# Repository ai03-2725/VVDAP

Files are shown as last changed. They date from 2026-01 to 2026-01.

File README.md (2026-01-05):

# VVDAP
Variable voltage isolated DAPLink programmer  

**Warning:** Currently untested.  
If testing, proceed at your own risk.  

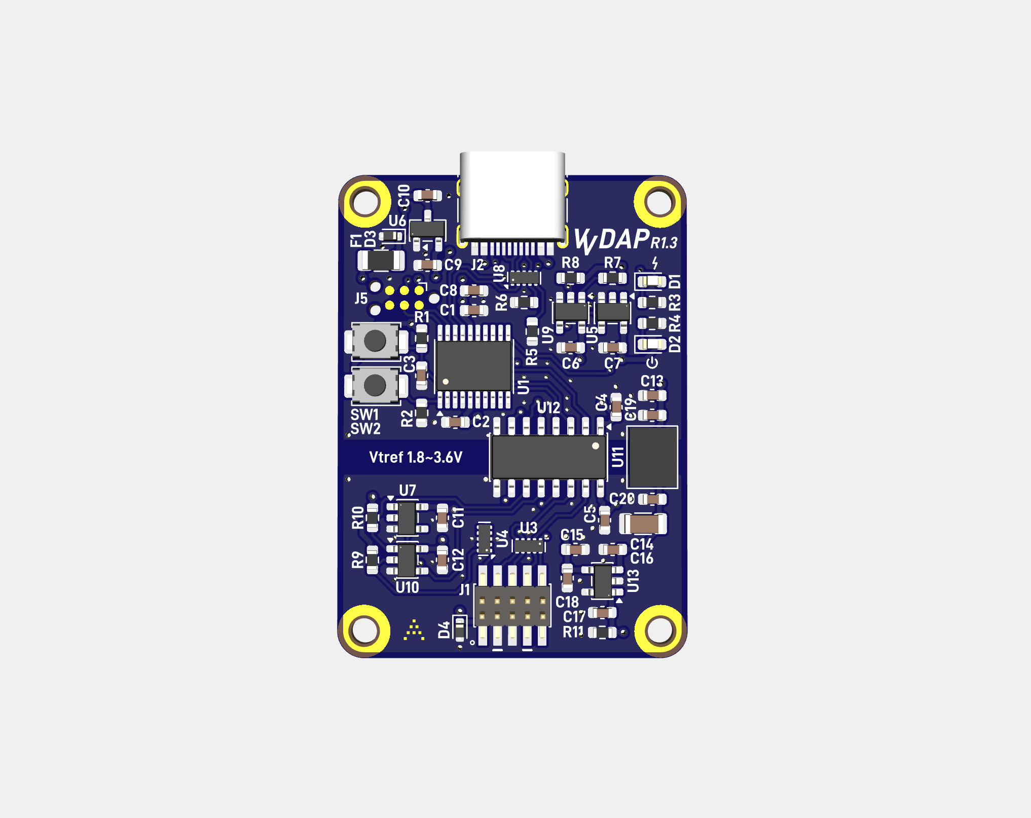
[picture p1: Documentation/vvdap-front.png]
Front

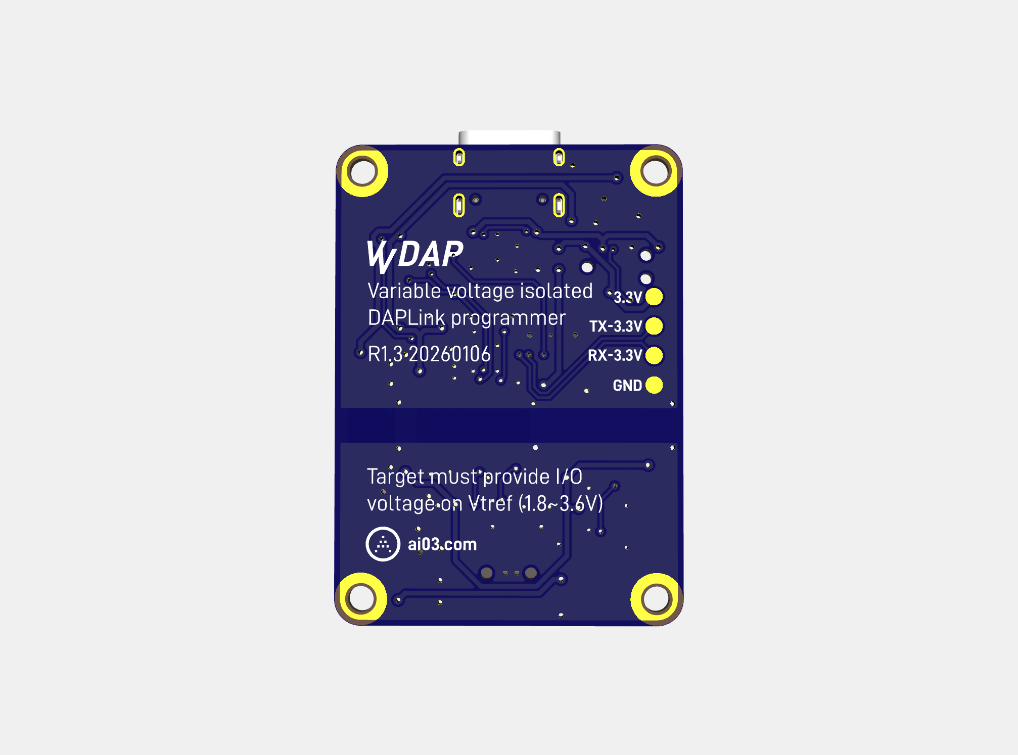
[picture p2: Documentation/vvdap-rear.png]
Rear


## Features
- DAPLink capabilities
  - [DAPLink](https://daplink.io) programming device for flashing Arm Cortex devices
  - Standard 10-pin (5x2) 1.27mm pitch Cortex debug connector for connection to target
  - Exposes UART pins - for future variable-voltage UART module addon via spring-loaded headers
- Variable voltage
  - Variable I/O voltage from 1.8 to 3.6V which self-adjusts to match the target VCC voltage provided on Vtref pin of debug header
- Protection
  - Full isolation between host and target to avoid ground loops or damage to host
  - ESD protection on USB lines and debug connector I/O
  - Polyfuse on USB VBUS
- Modern nice-to-haves
  - USB-C 
  - Fairly compact single-board solution
  - Relatively straightforward to solder at home with a reflow plate and (possibly 3D-printed) solder paste stencil
  - Very affordable (likely <15 USD) compared to the multi-hundred dollar commercial programmers

## Credits
This project builds upon the shoulders of giants - credits go to the following for nearly all of the heavy lifting.  
- [XIVN1987's DAPLink port](https://github.com/XIVN1987/DAPLink) to the CH32V203 microcontroller
- [XIVN1987's reference CH32V203/AT32F425 hardware design](https://oshwhub.com/xivn1987/daplink) for the above port
- [盐汽水-BD4USQ's DAPLink isolator design](https://oshwhub.com/yanqisui/dap-jlink-ge-li-diao-shi-kuo-zhan-ka) (and in turn the projects which it credits) which makes push-pull SWDIO possible over unidirectional isolators/transcievers 

## Changes from the above
- Swapped the digital I/O isolator to an ADuM162N capable of reaching low I/O voltage levels
- Added ESD protection on USB and I/O lines using TPD4E05U06 and ESD5Z5V0 TVS diodes
- Isolated voltage supply rail using the MIE1W0505/R05C1TF05S compact isolated DC/DC converter
- Added a TPS7B4250 tracking LDO to replicate the voltage provided on the Vtref pin of the debug header from the isolated supply rail, which in turn powers the secondary side of the I/O isolator and push-pull splitter
- Changed output connector to a 10-pin (2x5) 1.27mm pitch Cortex debug header
- Removed all power output capabilities 
  - Target should self-power to avoid potentially dangerous voltage mismatches, reverse voltage injection into circuitry not designed to withstand it, or voltage injection into batteries
- Misc component swaps

## Todo
- Produce and test
- Make a 3D printed case
- Make a variable voltage UART module which stacks onto the main board

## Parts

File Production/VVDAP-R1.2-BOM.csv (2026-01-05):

Reference | Qty | Value | DNP | Footprint | Description
C1,C2,C3,C4,C5,C6,C7,C11,C12,C17,C19,C20 | 12 | 0.1uF |  | Capacitor_SMD:C_0603_1608Metric | Ceramic capacitor, 0603, X7R, min 10V
C8,C9,C10,C15,C16,C18 | 6 | 1uF |  | Capacitor_SMD:C_0603_1608Metric | Ceramic capacitor, 0603, X7R, min 10V
C13 | 1 | 10uF |  | Capacitor_SMD:C_0603_1608Metric | Ceramic capacitor, 0603, X7R, min 10V
C14 | 1 | 22uF |  | Capacitor_SMD:C_1206_3216Metric | Ceramic capacitor, 1206, X7R, min 10V
D1 | 1 | LED-Red |  | LED_SMD:LED_0603_1608Metric | Light emitting diode, 0603, Red
D2 | 1 | LED-Green |  | LED_SMD:LED_0603_1608Metric | Light emitting diode, 0603, Green
D3,D4 | 2 | ESD5Z5V0 |  | Diode_SMD:D_SOD-523 | ESD Protection Diode, SOD-523
F1 | 1 | Polyfuse |  | Fuse:Fuse_1206_3216Metric | Resettable PTC fuse, 1A hold, 10V min
J1 | 1 | FTSH-105-01-L-DV-K |  | locallib:FTSH-105-01-L-DV-K | FTSH-105-01-L-DV-K 1.27mm pitch 2x5 pin connector
J2 | 1 | USB_C_Receptacle_USB2.0_16P |  | Connector_USB:USB_C_Receptacle_HRO_TYPE-C-31-M-12 | HRO TYPE-C-31-M-12 USB Type-C Receptacle connector
R1,R2 | 2 | 10k |  | Resistor_SMD:R_0603_1608Metric | Resistor, 0603
R3,R4,R7,R8,R9,R10 | 6 | 1k |  | Resistor_SMD:R_0603_1608Metric | Resistor, 0603
R5,R6 | 2 | 5.1k |  | Resistor_SMD:R_0603_1608Metric | Resistor, 0603
R11 | 1 | 1M |  | Resistor_SMD:R_0603_1608Metric | Resistor, 0603
SW1,SW2 | 2 | SW_Push |  | Button_Switch_SMD:SW_SPST_TS-1088-xR020 | TS-1088 family 3x4mm pushbuttons
U1 | 1 | CH32V203F6P6 |  | Package_SO:TSSOP-20_4.4x6.5mm_P0.65mm | CH32V203F6P6 Microcontroller
U3,U4,U8 | 3 | TPD4E05U06DQA |  | Package_SON:USON-10_2.5x1.0mm_P0.5mm | 4-Channel ESD Protection for Super-Speed USB 3.0 Interface, USON-10
U5,U7 | 2 | SN74LVC1G07DBVR |  | Package_TO_SOT_SMD:SOT-23-5 | Single Buffer Gate, Open Drain, Low-Voltage CMOS
U6 | 1 | XC6206P332MR |  | Package_TO_SOT_SMD:SOT-23-3 | Positive 60-250mA Low Dropout Regulator, Fixed Output, SOT-23
U9,U10 | 2 | SN74LVC1G66DBVR |  | Package_TO_SOT_SMD:SOT-23-5 | Single Bilateral Analog Switch, SOT-23-5/SC-70-5
U11 | 1 | MIE1W0505 |  | locallib:MIE1W0505 | Thin 4x5mm isolated DC-DC module with symmetrical pads - MIE1W0505, R05C1TF05S, and equivalents
U12 | 1 | ADuM162N1BRZ |  | Package_SO:SOIC-16_3.9x9.9mm_P1.27mm | ADuM162N1BRZ digital I/O isolator
U13 | 1 | TPS7B4250 |  | Package_TO_SOT_SMD:SOT-23-5 | TPS7B4250 tracking LDO
Total | 52

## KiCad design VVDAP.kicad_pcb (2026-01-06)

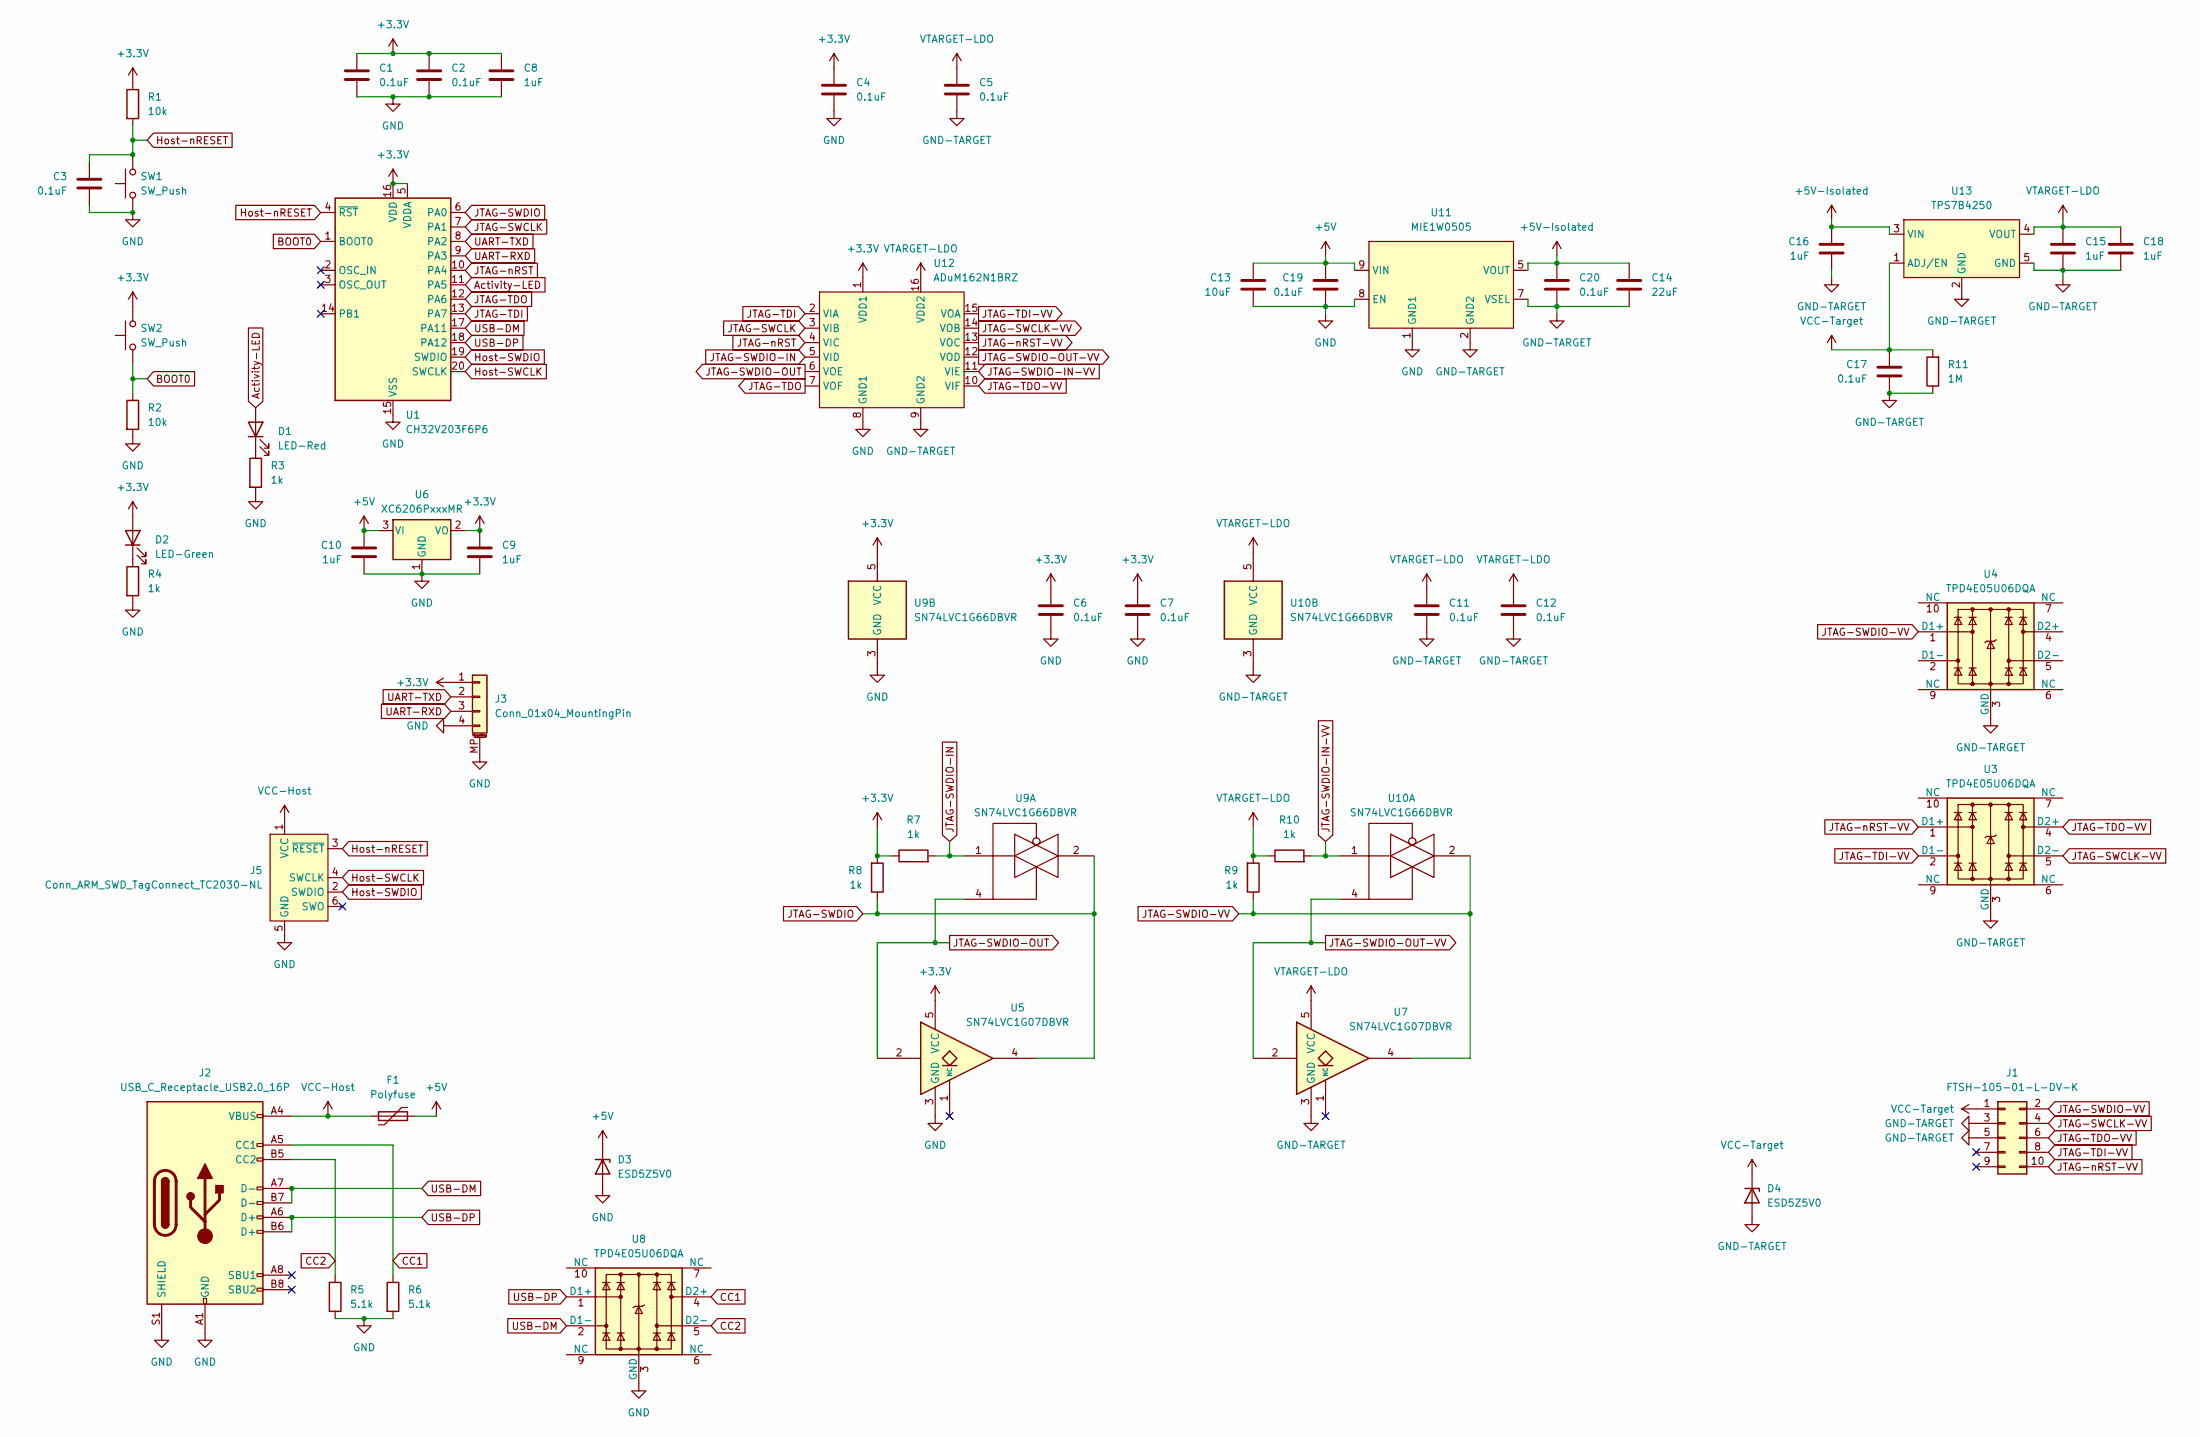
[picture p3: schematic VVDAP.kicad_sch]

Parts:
C1, C2, C3, C4, C5, C6, C7, C11, C12, C17, C19, C20: 0.1uF; C_0603_1608Metric
C8, C9, C10, C15, C16, C18: 1uF; C_0603_1608Metric
C13: 10uF; C_0603_1608Metric
C14: 22uF; C_1206_3216Metric
D1: LED-Red; LED_0603_1608Metric
D2: LED-Green; LED_0603_1608Metric
D3, D4: ESD5Z5V0; D_SOD-523
F1: Polyfuse; Fuse_1206_3216Metric
J1: FTSH-105-01-L-DV-K
J2: USB_C_Receptacle_USB2.0_16P; USB_C_Receptacle_HRO_TYPE-C-31-M-12
J3: Conn_01x04_MountingPin; PogoReceiver-2.54-4
J5: Conn_ARM_SWD_TagConnect_TC2030-NL; Tag-Connect_TC2030-IDC-NL_2x03_P1.27mm_Vertical
R1, R2: 10k; R_0603_1608Metric
R3, R4, R7, R8, R9, R10: 1k; R_0603_1608Metric
R5, R6: 5.1k; R_0603_1608Metric
R11: 1M; R_0603_1608Metric
SW1, SW2: SW_Push; SW_SPST_TS-1088-xR020
U1: CH32V203F6P6; TSSOP-20_4.4x6.5mm_P0.65mm
U3, U4, U8: TPD4E05U06DQA; USON-10_2.5x1.0mm_P0.5mm
U5, U7: SN74LVC1G07DBVR; SOT-23-5
U6: XC6206PxxxMR; SOT-23-3
U9, U10: SN74LVC1G66DBVR; SOT-23-5
U11: MIE1W0505
U12: ADuM162N1BRZ; SOIC-16_3.9x9.9mm_P1.27mm
U13: TPS7B4250; SOT-23-5

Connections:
+3.3V: C1.1, C2.1, C4.1, C6.1, C7.1, C8.1, C9.1, D2.2 (A), J3.1, R1.1, R7.1, R8.2, SW2.2, U1.5 (VDDA), U1.16 (VDD), U5.5 (VCC), U6.2 (VO), U9.5 (VCC), U12.1 (VDD1)
+5V: C10.1, C13.1, C19.1, D3.1 (K), F1.2, U6.3 (VI), U11.9 (VIN), U11.10 (VIN)
+5V-Isolated: C14.1, C16.1, C20.1, U11.5 (VOUT), U11.6 (VOUT), U13.3 (VIN)
Activity-LED: D1.2 (A), U1.11 (PA5)
BOOT0: R2.1, SW2.1, U1.1 (BOOT0)
CC1: J2.A5 (CC1), R6.1, U8.4 (D2+)
CC2: J2.B5 (CC2), R5.1, U8.5 (D2-)
GND: C1.2, C2.2, C3.2, C4.2, C6.2, C7.2, C8.2, C9.2, C10.2, C13.2, C19.2, D3.2 (A), J2.A1 (GND), J2.A12 (GND), J2.B1 (GND), J2.B12 (GND), J2.S1 (SHIELD), J3.4, J3.MP (MountPin), J5.5 (GND), R2.2, R3.2, R4.2, R5.2, R6.2, SW1.1, U1.15 (VSS), U5.3 (GND), U6.1 (GND), U8.3 (GND), U8.8 (GND), U9.3 (GND), U11.1 (GND1), U11.8 (EN), U11.11 (GND1), U11.12 (GND1), U12.8 (GND1)
GND-TARGET: C5.2, C11.2, C12.2, C14.2, C15.2, C16.2, C17.2, C18.2, C20.2, D4.2 (A), J1.3, J1.5, R11.1, U3.3 (GND), U3.8 (GND), U4.3 (GND), U4.8 (GND), U7.3 (GND), U10.3 (GND), U11.2 (GND2), U11.3 (GND2), U11.4 (GND2), U11.7 (VSEL), U12.9 (GND2), U13.2 (GND), U13.5 (GND)
Host-SWCLK: J5.4 (SWCLK), U1.20 (SWCLK)
Host-SWDIO: J5.2 (SWDIO), U1.19 (SWDIO)
Host-nRESET: C3.1, J5.3 (~RESET), R1.2, SW1.2, U1.4 (~RST)
JTAG-SWCLK: U1.7 (PA1), U12.3 (VIB)
JTAG-SWCLK-VV: J1.4, U3.5 (D2-), U12.14 (VOB)
JTAG-SWDIO: R8.1, U1.6 (PA0), U5.4, U9.2
JTAG-SWDIO-IN: R7.2, U9.1, U12.5 (VID)
JTAG-SWDIO-IN-VV: R10.2, U10.1, U12.11 (VIE)
JTAG-SWDIO-OUT: U5.2, U9.4, U12.6 (VOE)
JTAG-SWDIO-OUT-VV: U7.2, U10.4, U12.12 (VOD)
JTAG-SWDIO-VV: J1.2, R9.1, U4.1 (D1+), U7.4, U10.2
JTAG-TDI: U1.13 (PA7), U12.2 (VIA)
JTAG-TDI-VV: J1.8, U3.2 (D1-), U12.15 (VOA)
JTAG-TDO: U1.12 (PA6), U12.7 (VOF)
JTAG-TDO-VV: J1.6, U3.4 (D2+), U12.10 (VIF)
JTAG-nRST: U1.10 (PA4), U12.4 (VIC)
JTAG-nRST-VV: J1.10, U3.1 (D1+), U12.13 (VOC)
unnamed: D1.1 (K), R3.1
unnamed: D2.1 (K), R4.1
UART-RXD: J3.3, U1.9 (PA3)
UART-TXD: J3.2, U1.8 (PA2)
USB-DM: J2.A7 (D-), J2.B7 (D-), U1.17 (PA11), U8.2 (D1-)
USB-DP: J2.A6 (D+), J2.B6 (D+), U1.18 (PA12), U8.1 (D1+)
VCC-Host: F1.1, J2.A4 (VBUS), J2.A9 (VBUS), J2.B4 (VBUS), J2.B9 (VBUS), J5.1 (VCC)
VCC-Target: C17.1, D4.1 (K), J1.1, R11.2, U13.1 (ADJ/EN)
VTARGET-LDO: C5.1, C11.1, C12.1, C15.1, C18.1, R9.2, R10.1, U7.5 (VCC), U10.5 (VCC), U12.16 (VDD2), U13.4 (VOUT)

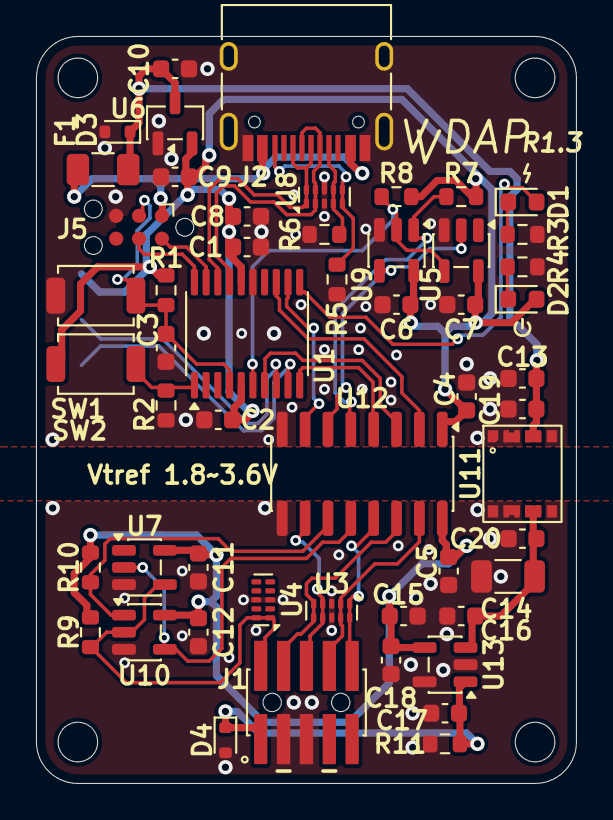
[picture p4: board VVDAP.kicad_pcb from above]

Board: 2 copper layers, 30.0 x 41.5 mm, 54 parts (1 on the bottom side), 35 nets.

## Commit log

2026-01-06 Update renders; adjust edge cuts slightly
    [VVDAP-B_Cu.gbl, VVDAP-B_Mask.gbs, VVDAP-B_Paste.gbp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]
2026-01-06 Update screw pads
    [VVDAP-B_Cu.gbl, VVDAP-B_Mask.gbs, VVDAP-B_Paste.gbp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]
2026-01-06 Revert outline to G1 due to visual issues
    [VVDAP-B_Cu.gbl, VVDAP-B_Mask.gbs, VVDAP-B_Paste.gbp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]
